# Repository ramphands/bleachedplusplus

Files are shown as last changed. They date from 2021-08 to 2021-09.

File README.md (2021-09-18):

# bleached++
slightly expanded and simplified version of the original Bleached PCB design by [andr-ew](https://github.com/andr-ew/bleached)

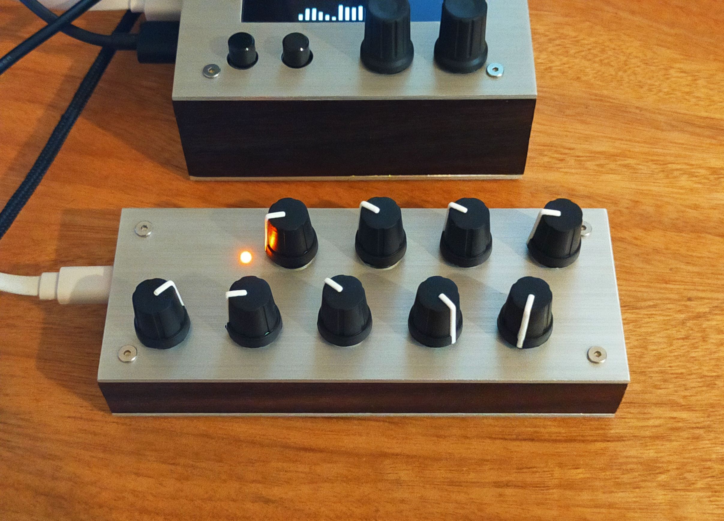
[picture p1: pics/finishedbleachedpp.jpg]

Bleached++ in operation

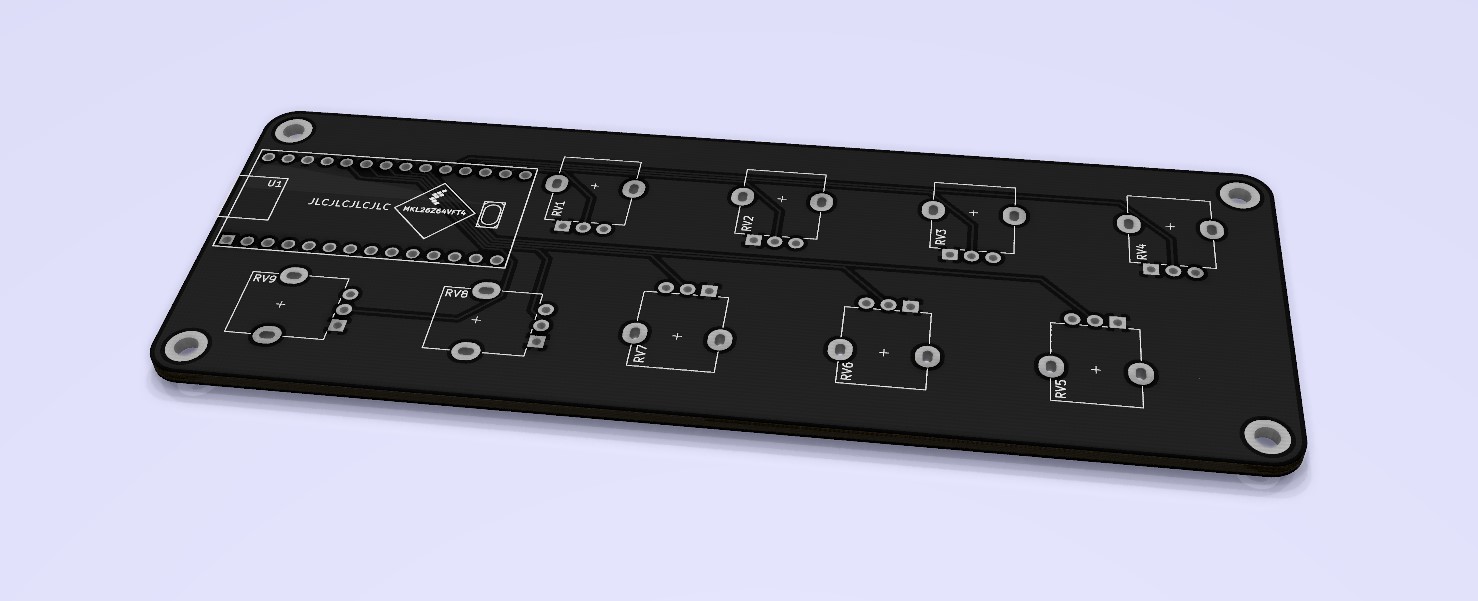
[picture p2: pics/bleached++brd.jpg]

Render of the board

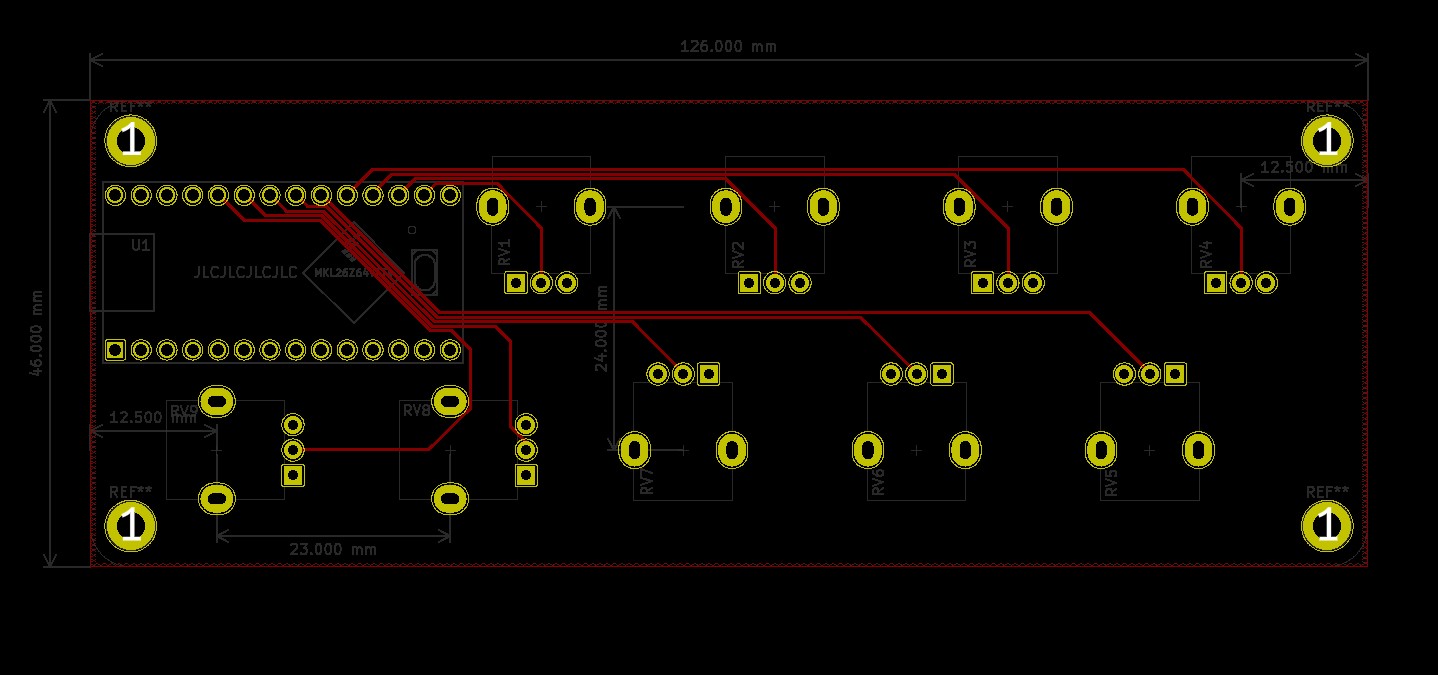
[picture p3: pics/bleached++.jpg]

PCB layout with dimensions

## BOM
### board:
1x TeensyLC

2x 14-pin pin headers.

9x 10K linear potentiometers

### mounting HW:
4x 10mm M2.5 female-female standoffs - to be used between the board and the top panel

4x 5mm* M2.5 male-female standoffs  - to be used between the board and the bottom panel (*any length >3mm would be fine)

8x M2.5 5mm length screws

## PCBs

Gerbers are available as a .zip file in the GBR directory.  Simply provide the .zip file to a fabrication house.  JLCPCB is perhaps the most inexpensive.  If using JLCPCB, be sure to use the "specify a location" option to place the unsightly order code under the Teensy, as seen in the render.  The option looks like this:



## Firmware

Firmware has been modified from the original Bleached firmware to include the two additional potentiometers.

Also, an additional dual-bank firmware is available incorporating the changes made by [mat](https://github.com/justmat/) which allows for a dual 8-bank configuration.  The active bank is selectable with the lower-left potentiometer, with feedback provided by the Teensy LED.

## Top/bottom panels/enclosure

An SVG file is provided for making your own top/bottom panels.  Use Inkscape or other SVG-reading software to view the file.  All elements are seperated into individual layers, so you are able to hide/show the appropriate information.  In my case, I make only the outline and all the centrepunch marking crosses visible, then save as a PDF and print at a 1:1 size. I use this as a template for cutting and drilling a blank top panel.  I then hide the marking crosses for the LED and potentiometers, repeat the PDF process and use the resultant template for the bottom panel.

## NOTE

Design has been tested as of 16th Sept 2021 and works as intended with the firmware.

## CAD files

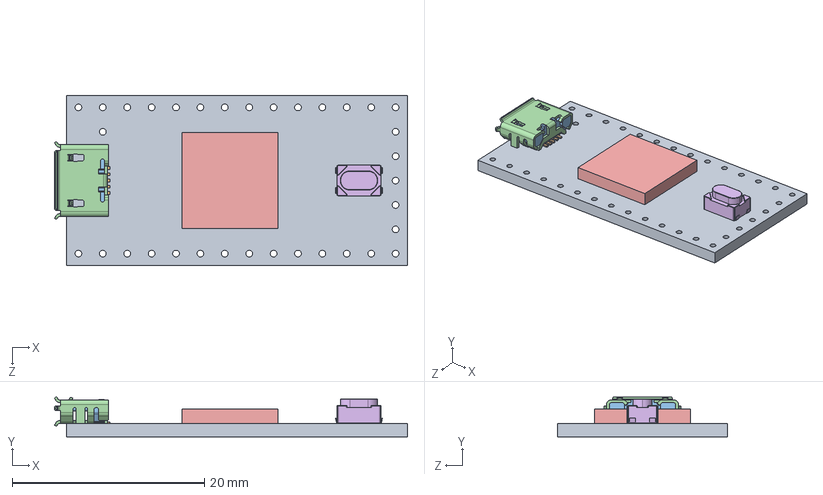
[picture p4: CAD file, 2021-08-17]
bleached ++ kicad files/teensy.pretty-master/Teensy_4.0_Assembly.STEP
36.8 x 4.12 x 17.7 mm
Teensy_4.0_PCB
Micro USB-B Female 5Pin SMD
NXP iMXRT1062
SKRPACE010 v4

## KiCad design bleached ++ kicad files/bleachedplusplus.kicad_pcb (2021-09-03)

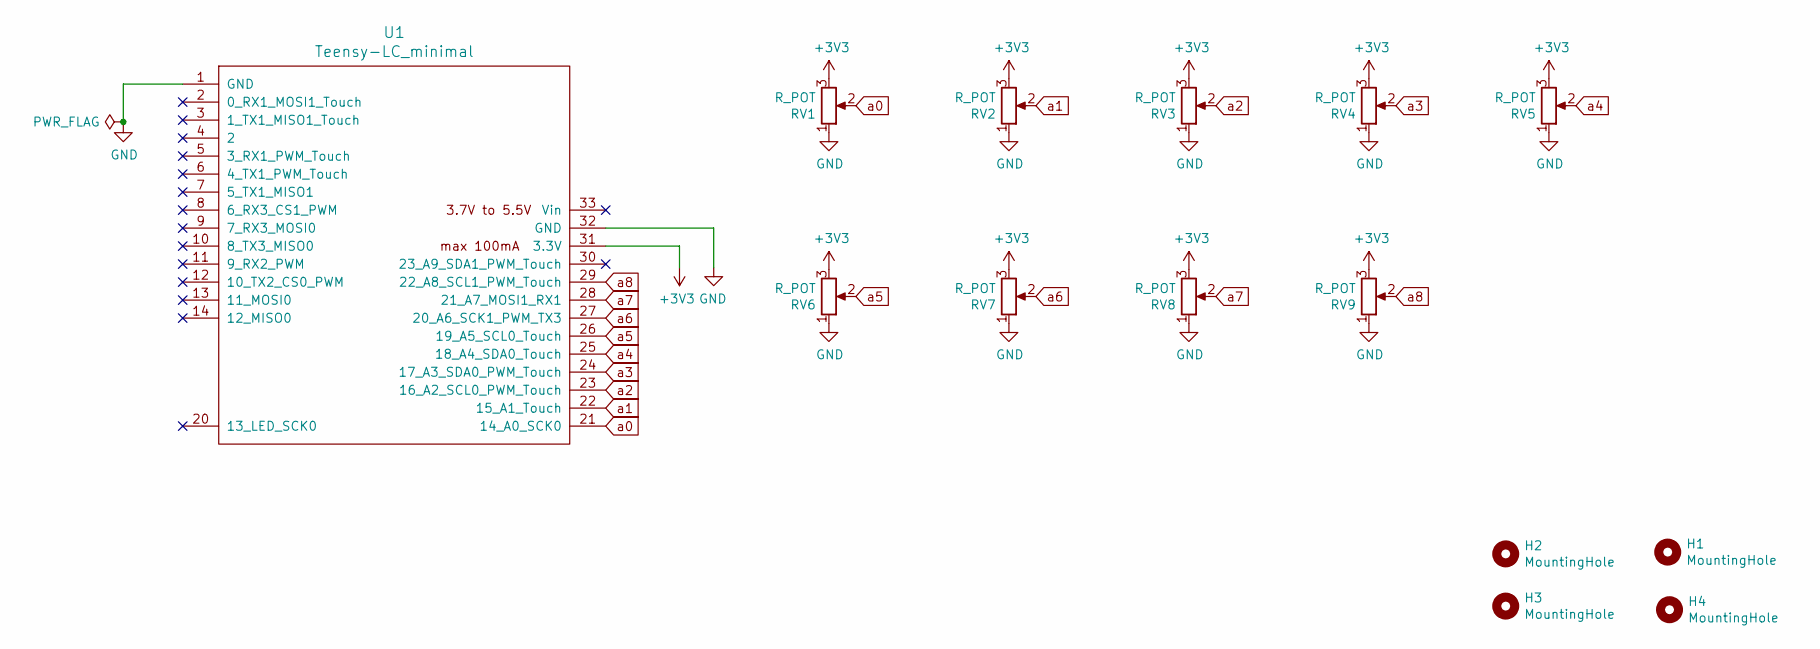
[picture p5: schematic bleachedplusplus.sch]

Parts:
H1, H2, H3, H4: MountingHole; MountingHole_2.7mm_M2.5_DIN965_Pad
RV1, RV2, RV3, RV4, RV5, RV6, RV7, RV8, RV9: R_POT; Potentiometer_Alpha_RD901F-40-00D_Single_Vertical
U1: Teensy-LC_minimal; Teensy_LC_minimal

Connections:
+3V3: RV1.3, RV2.3, RV3.3, RV4.3, RV5.3, RV6.3, RV7.3, RV8.3, RV9.3, U1.31 (3.3V)
GND: RV1.1, RV2.1, RV3.1, RV4.1, RV5.1, RV6.1, RV7.1, RV8.1, RV9.1, U1.1 (GND), U1.32 (GND)
a0: RV1.2, U1.21 (14_A0_SCK0)
a1: RV2.2, U1.22 (15_A1_Touch)
a2: RV3.2, U1.23 (16_A2_SCL0_PWM_Touch)
a3: RV4.2, U1.24 (17_A3_SDA0_PWM_Touch)
a4: RV5.2, U1.25 (18_A4_SDA0_Touch)
a5: RV6.2, U1.26 (19_A5_SCL0_Touch)
a6: RV7.2, U1.27 (20_A6_SCK1_PWM_TX3)
a7: RV8.2, U1.28 (21_A7_MOSI1_RX1)
a8: RV9.2, U1.29 (22_A8_SCL1_PWM_Touch)

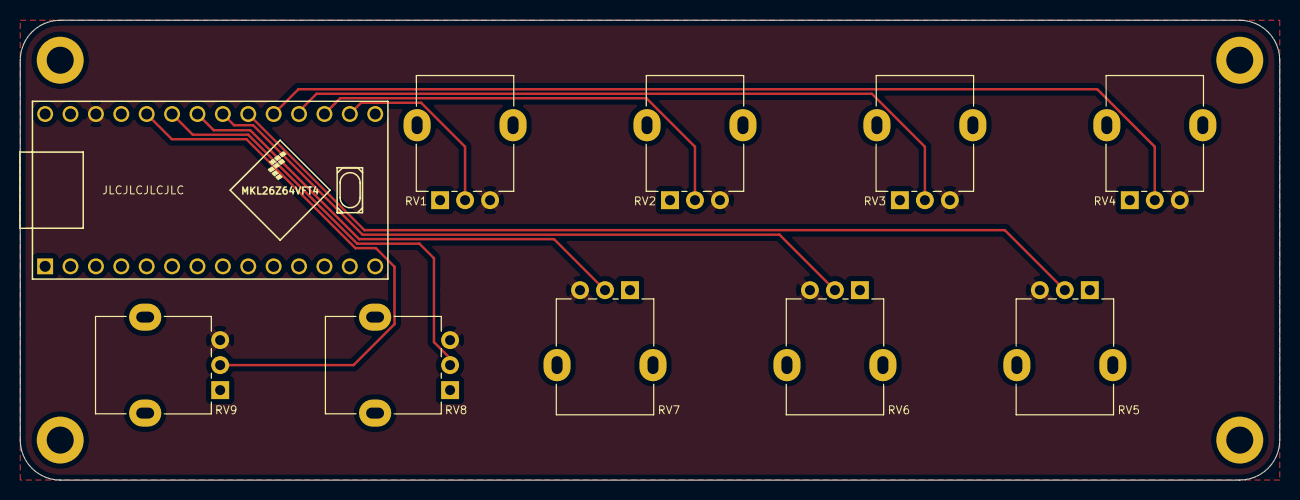
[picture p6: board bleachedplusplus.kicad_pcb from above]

Board: 2 copper layers, 126.0 x 46.0 mm, 14 parts (0 on the bottom side), 11 nets.

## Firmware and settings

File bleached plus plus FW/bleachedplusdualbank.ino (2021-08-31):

/* Sonoclast pd knobs for TeensyLC
 
  * Originally modified by andrew for bleached (Teensy 3.2) 02/22/2019
  * Modified by mat to include a dual-bank mode 7/26/2020
  * Modified by ramphands for bleached++ (Teensy LC) 24/Aug/2021
 
   Copyright March 2019 - havencking@gmail.com
     This program is free software: you can redistribute it and/or modify
     it under the terms of the GNU General Public License as published by
     the Free Software Foundation, either version 3 of the License, or
     (at your option) any later version.
     This program is distributed in the hope that it will be useful,
     but WITHOUT ANY WARRANTY; without even the implied warranty of
     MERCHANTABILITY or FITNESS FOR A PARTICULAR PURPOSE.  See the
     GNU General Public License for more details.
     You should have received a copy of the GNU General Public License
     along with this program.  If not, see <http://www.gnu.org/licenses/>.
   The Sonoclast pd knobs is a MIDI CC controller designed particularly
   for use with pure data.  However it could be used to control any
   software that recognizes MIDI CC messages.  Customize the Control
   Channels below if you like.
   Compiling instructions:
   Follow these instructions to install the Arduino software and Tensyduino:
   https://www.pjrc.com/teensy/td_download.html
   In the Arduino software be sure to select the following:
   Tools > Board > TeensyLC
   Tools > USB Type > Serial + MIDI
*/

// led state
bool led_state = false;

// Map MIDI CC channels to knobs numbered left to right.
#define CC01  102
#define CC02  103
#define CC03  104
#define CC04  105
#define CC05  106
#define CC06  107
#define CC07  108
#define CC08  109
#define CC09  110
#define CC10  111
#define CC11  112
#define CC12  113
#define CC13  114
#define CC14  115
#define CC15  116
#define CC16  117
#define CC17  118



// Map the TeensyLC pins to each potentiometer numbered left to right.
#define POT01 8
#define POT02 7
#define POT03 6
#define POT04 5
#define POT05 4
#define POT06 0
#define POT07 1
#define POT08 2
#define POT09 3


// Use this MIDI channel.
#define MIDI_CHANNEL 1

// Send MIDI CC messages for all 9 knobs after the main loop runs this many times.
// This prevents having to twiddle the knobs to update the receiving end.
// 10,000 loops is roughly 10 seconds.
//#define LOOPS_PER_REFRESH 10000

// potentiometer read parameters
#define POT_BIT_RES         10 // 10 works, 7-16 is valid
#define POT_NUM_READS       32 // 32 works

// Track the knob state.
uint16_t prev_pot_val[9] = {0xffff,
                             0xffff, 0xffff, 0xffff, 0xffff, 0xffff, 0xffff, 0xffff, 0xffff
                            };

// an array of potentiometer pins
uint8_t pot[9] = {POT01,
                   POT02, POT03, POT04, POT05, POT06, POT07, POT08, POT09
                  };

// an array of CC numbers
uint8_t cc_set_1[8] = {
                  CC02, CC03, CC04, CC05, CC06, CC07, CC08, CC09
                 };

// an array of CC numbers
uint8_t cc_set_2[8] = {
                  CC10, CC11, CC12, CC13, CC14, CC15, CC16, CC17
                 };
// Prevent jitter when reading the potentiometers.
// Higher value is less chance of jitter but also less precision.
const uint8_t nbrhd = 5;

// Count the number of main loops.
uint16_t loop_count = 0;

void setup() {
  // serial monitoring for debugging
  Serial.begin(38400);
  
   // led pin mode
  pinMode(13, OUTPUT);

  // potentiometers
  analogReadResolution(POT_BIT_RES);
  analogReadAveraging(POT_NUM_READS);
}


void loop() {
  // Read each knob, and send MIDI CC only if the value changed.
  for (uint8_t i = 0; i < 9; i++) {
    uint16_t pot_val = analogRead(pot[i]);
    if ((pot_val < prev_pot_val[i] - nbrhd) ||
        (pot_val > prev_pot_val[i] + nbrhd)) {
          // use pot1 to control led  
          if (i == 0 and pot_val > 511) {
            led_state = true;
            digitalWrite(13, HIGH);
          }
          else if (i == 0 and pot_val < 511) {
            led_state = false;
            digitalWrite(13, LOW);
          }
          // use led state to decide which cc_set to use
          if (i != 0 and (led_state)) {
            //Serial.print(cc_set_2[i - 1]);
            usbMIDI.sendControlChange(cc_set_2[i - 1], pot_val >> (POT_BIT_RES - 7), MIDI_CHANNEL);
          }
          else if (i != 0 and not (led_state)) {
            //Serial.print(cc_set_1[i - 1]);
            usbMIDI.sendControlChange(cc_set_1[i - 1], pot_val >> (POT_BIT_RES - 7), MIDI_CHANNEL);
          }
          //Serial.println("");
          prev_pot_val[i] = pot_val;
    }
  }
  while (usbMIDI.read()) {
    // read & ignore incoming messages
  }
}

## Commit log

2021-08-25 Add files via upload
    Contains SVG file for making your own case panels.
    Use the layer visibility options to select the relevant options ie hiding the LED/potentiometer drill holes when printing/exporting the "bottom" panel.
2021-08-31 Add files via upload
    fixed potentiometer rotation
    [bleachedplusplus.kicad_pcb, bleachedplusplus.sch]
